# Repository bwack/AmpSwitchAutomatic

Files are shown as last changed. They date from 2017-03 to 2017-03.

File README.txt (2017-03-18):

Amp Switch Automatic,
6 amplifiers connected to one pair of stereo speakers with
automatic switching.

Realized with 1970-80s digital logic technology on two stripboards, and
a project box with 28 speaker terminals on it and a 5V power input.

Cheepo auto 1:1 600:600 ohm audio transformers were used to galvanically
isolate the amplifiers, and to pass audio to the detector circuits (lm339).
The relays switch the amplifiers in one at a time. If there is audio on
more than one amplifier, the amp switch sticks to the currently switched amp,
just to keep the box from switching too much. It is not intended to mix,
just switch though.

Bwack, 2017

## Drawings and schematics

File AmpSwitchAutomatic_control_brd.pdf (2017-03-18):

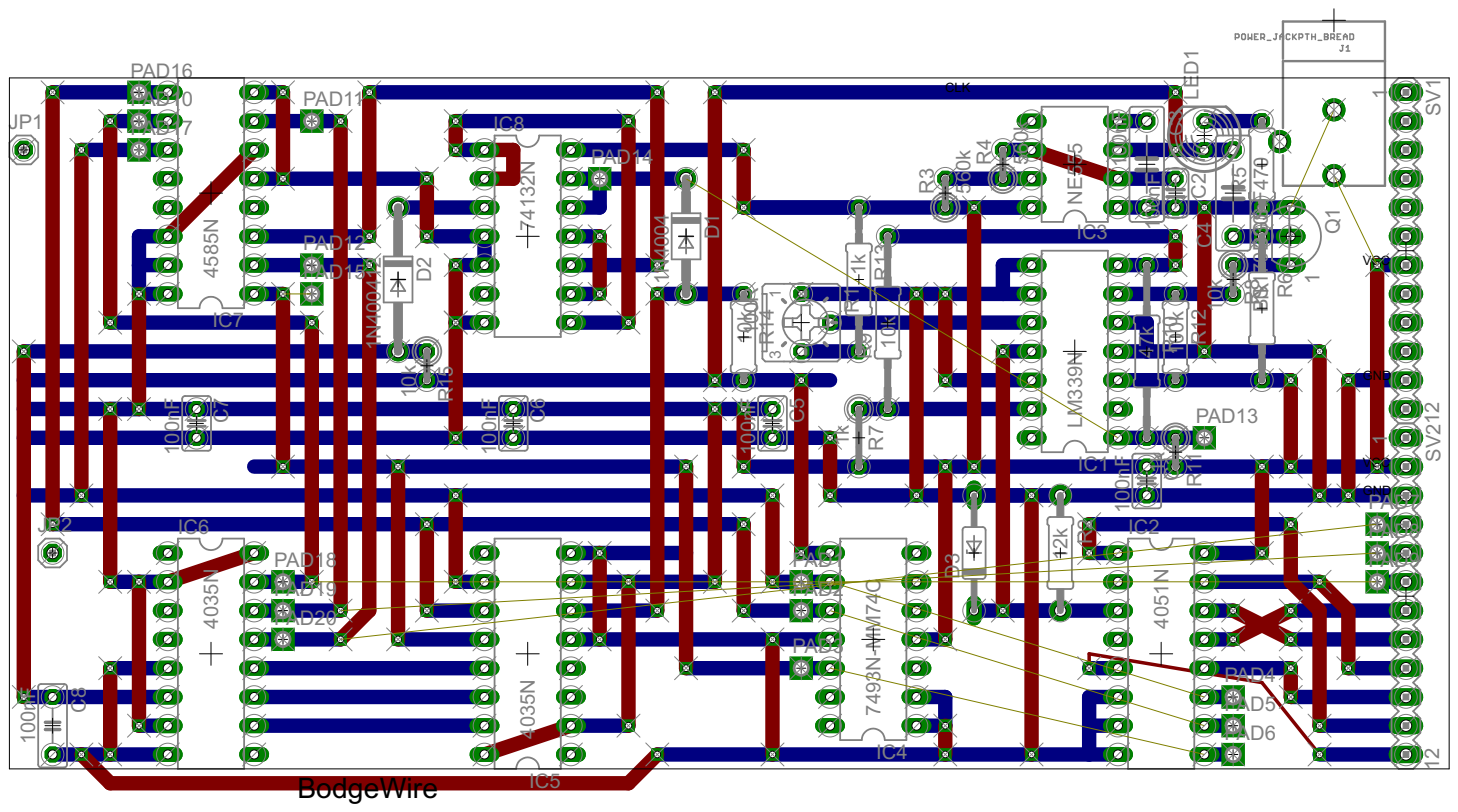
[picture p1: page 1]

1 12 1 12 3 1 1 SV1 SV2 IC1 IC2 R2 C1 IC3 R3R4 C2 C3 LED1 R5 R6 C4 R7 R8 R9R10 R11 R1 R2 1 R13 IC4 IC5 R14 D1 IC6 IC7 IC8 D2 R15 C5C6C7 Q1 PAD1 PAD2 PAD3 PAD4 PAD5 PAD6 PAD7 PAD8 PAD9 PAD10 PAD11 PAD12 D3 PAD13 PAD14 PAD15 PAD16 PAD17 PAD18 PAD19 PAD20 JP1JP2 C8 LM339N 4051N 12k 100nF NE555 560k560k 100nF 100nF 470 1k 330nF 1k 10k 10k 47k 1k 100k 100R 1k 7493N-MM74C 4035N 10k 1N4004 4035N 4585N74132N 1N400412 10k 100nF 100nF 100nF BS170DGS 100nF VCC VCC GND GND CLK BodgeWire

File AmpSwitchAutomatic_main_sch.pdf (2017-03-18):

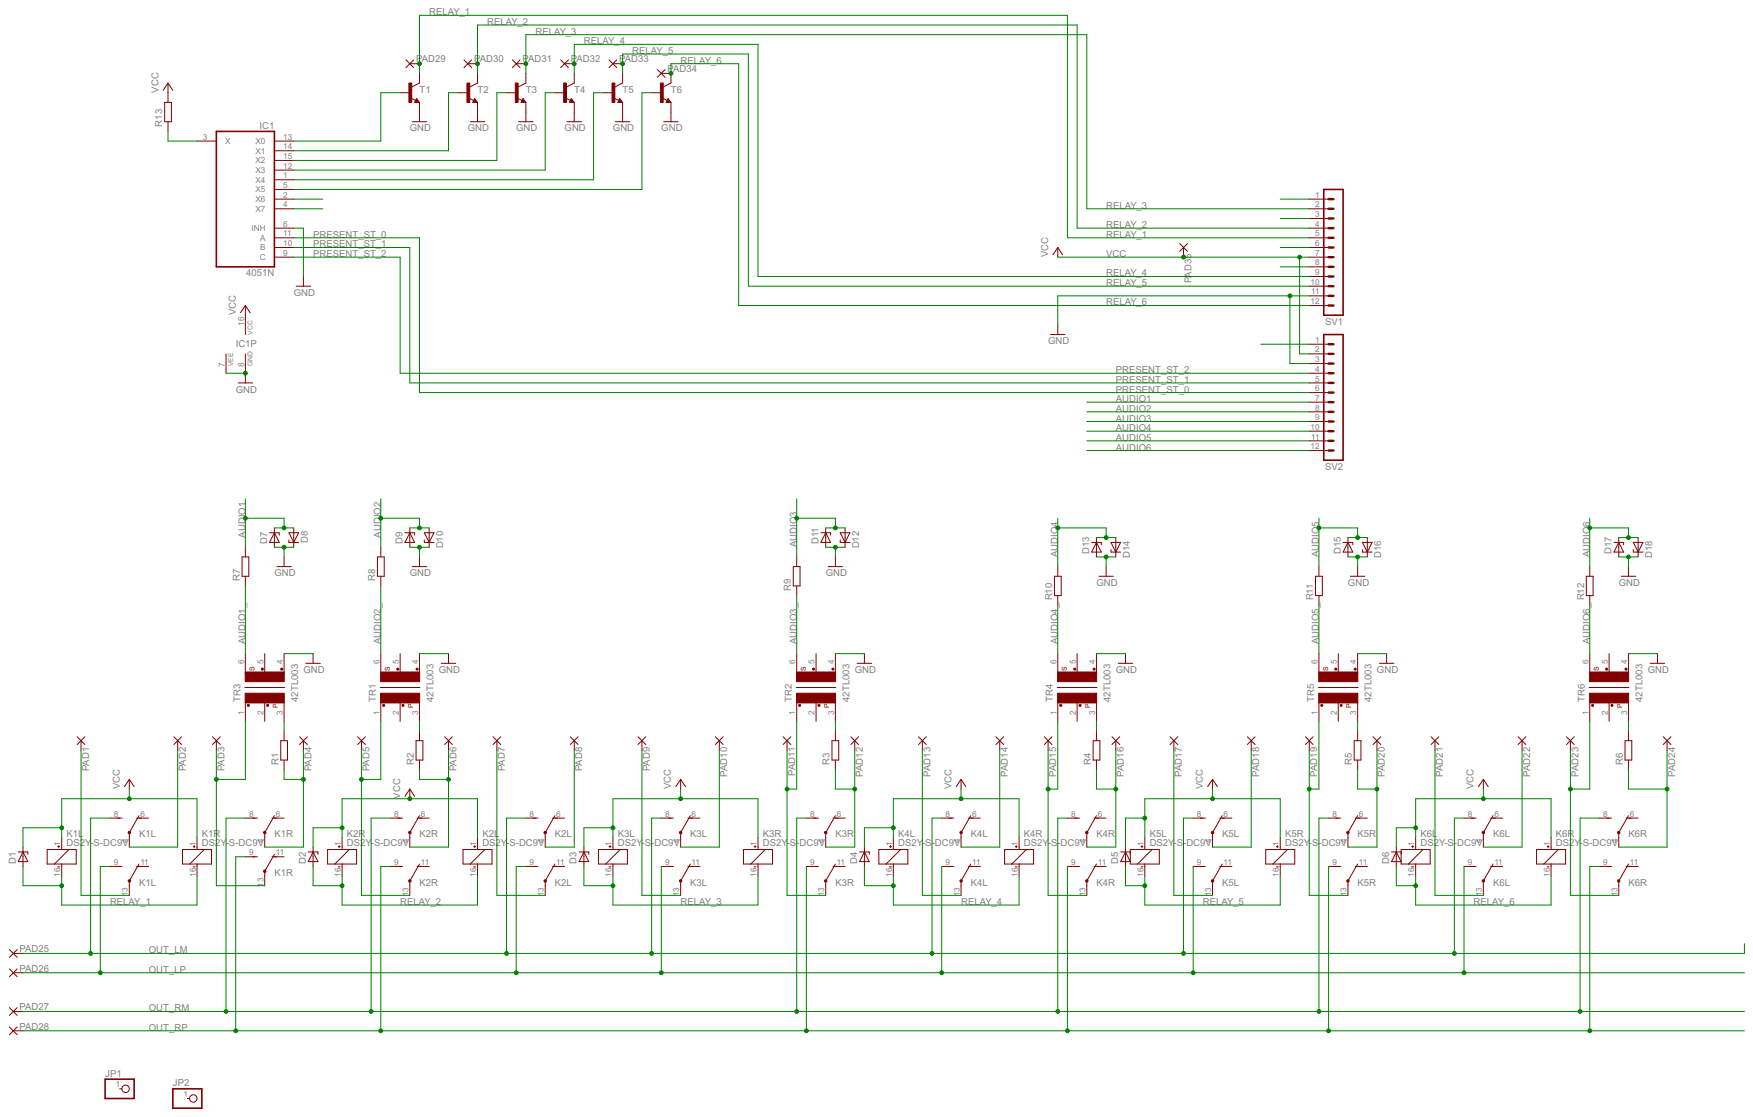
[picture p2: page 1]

RELAY_3

RELAY_4

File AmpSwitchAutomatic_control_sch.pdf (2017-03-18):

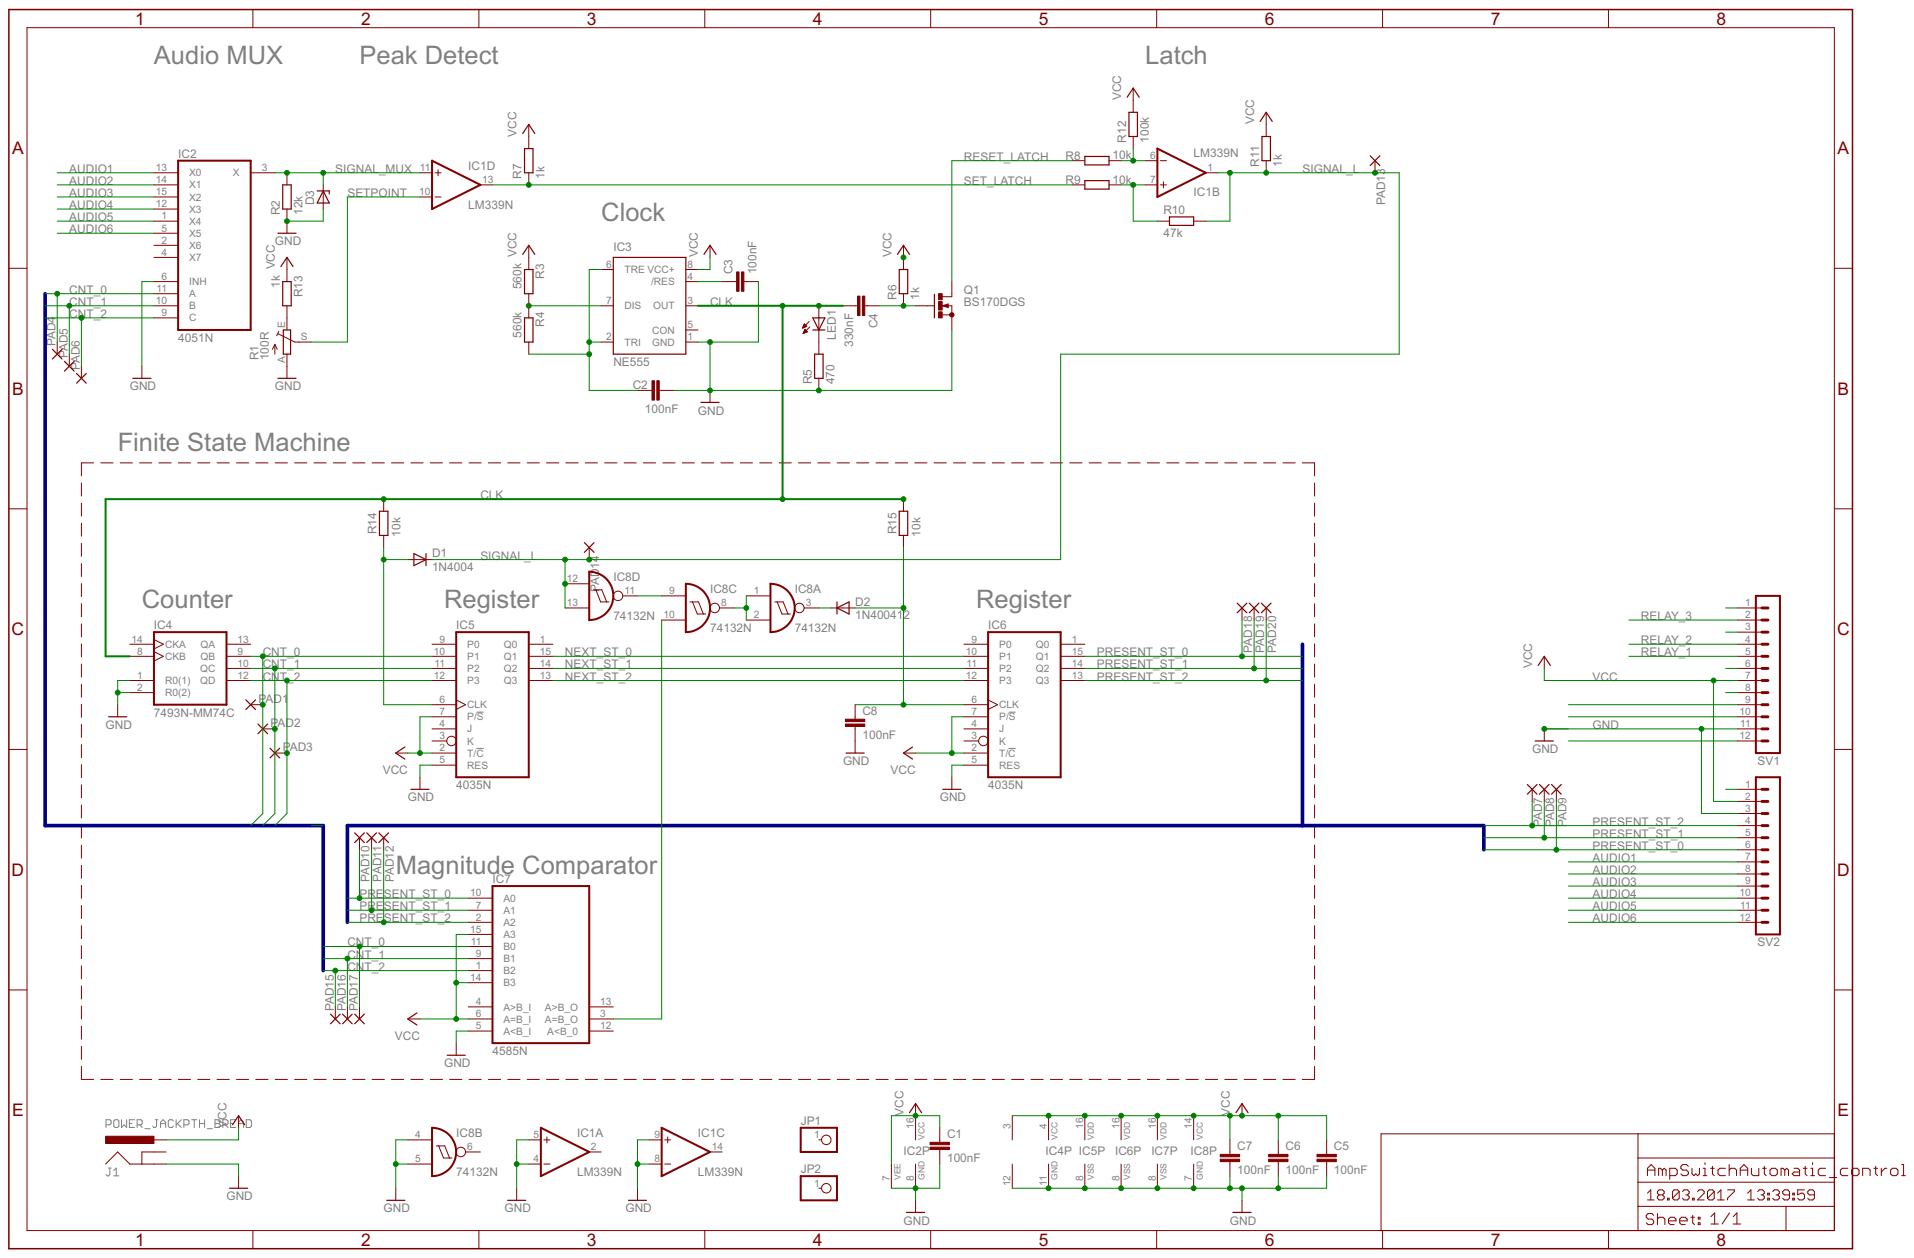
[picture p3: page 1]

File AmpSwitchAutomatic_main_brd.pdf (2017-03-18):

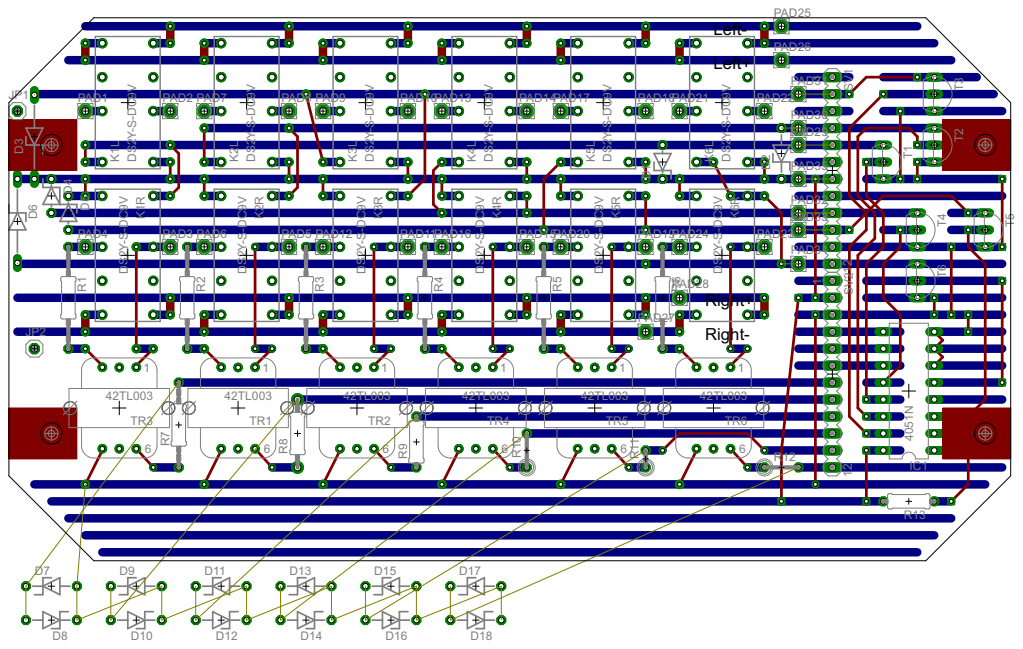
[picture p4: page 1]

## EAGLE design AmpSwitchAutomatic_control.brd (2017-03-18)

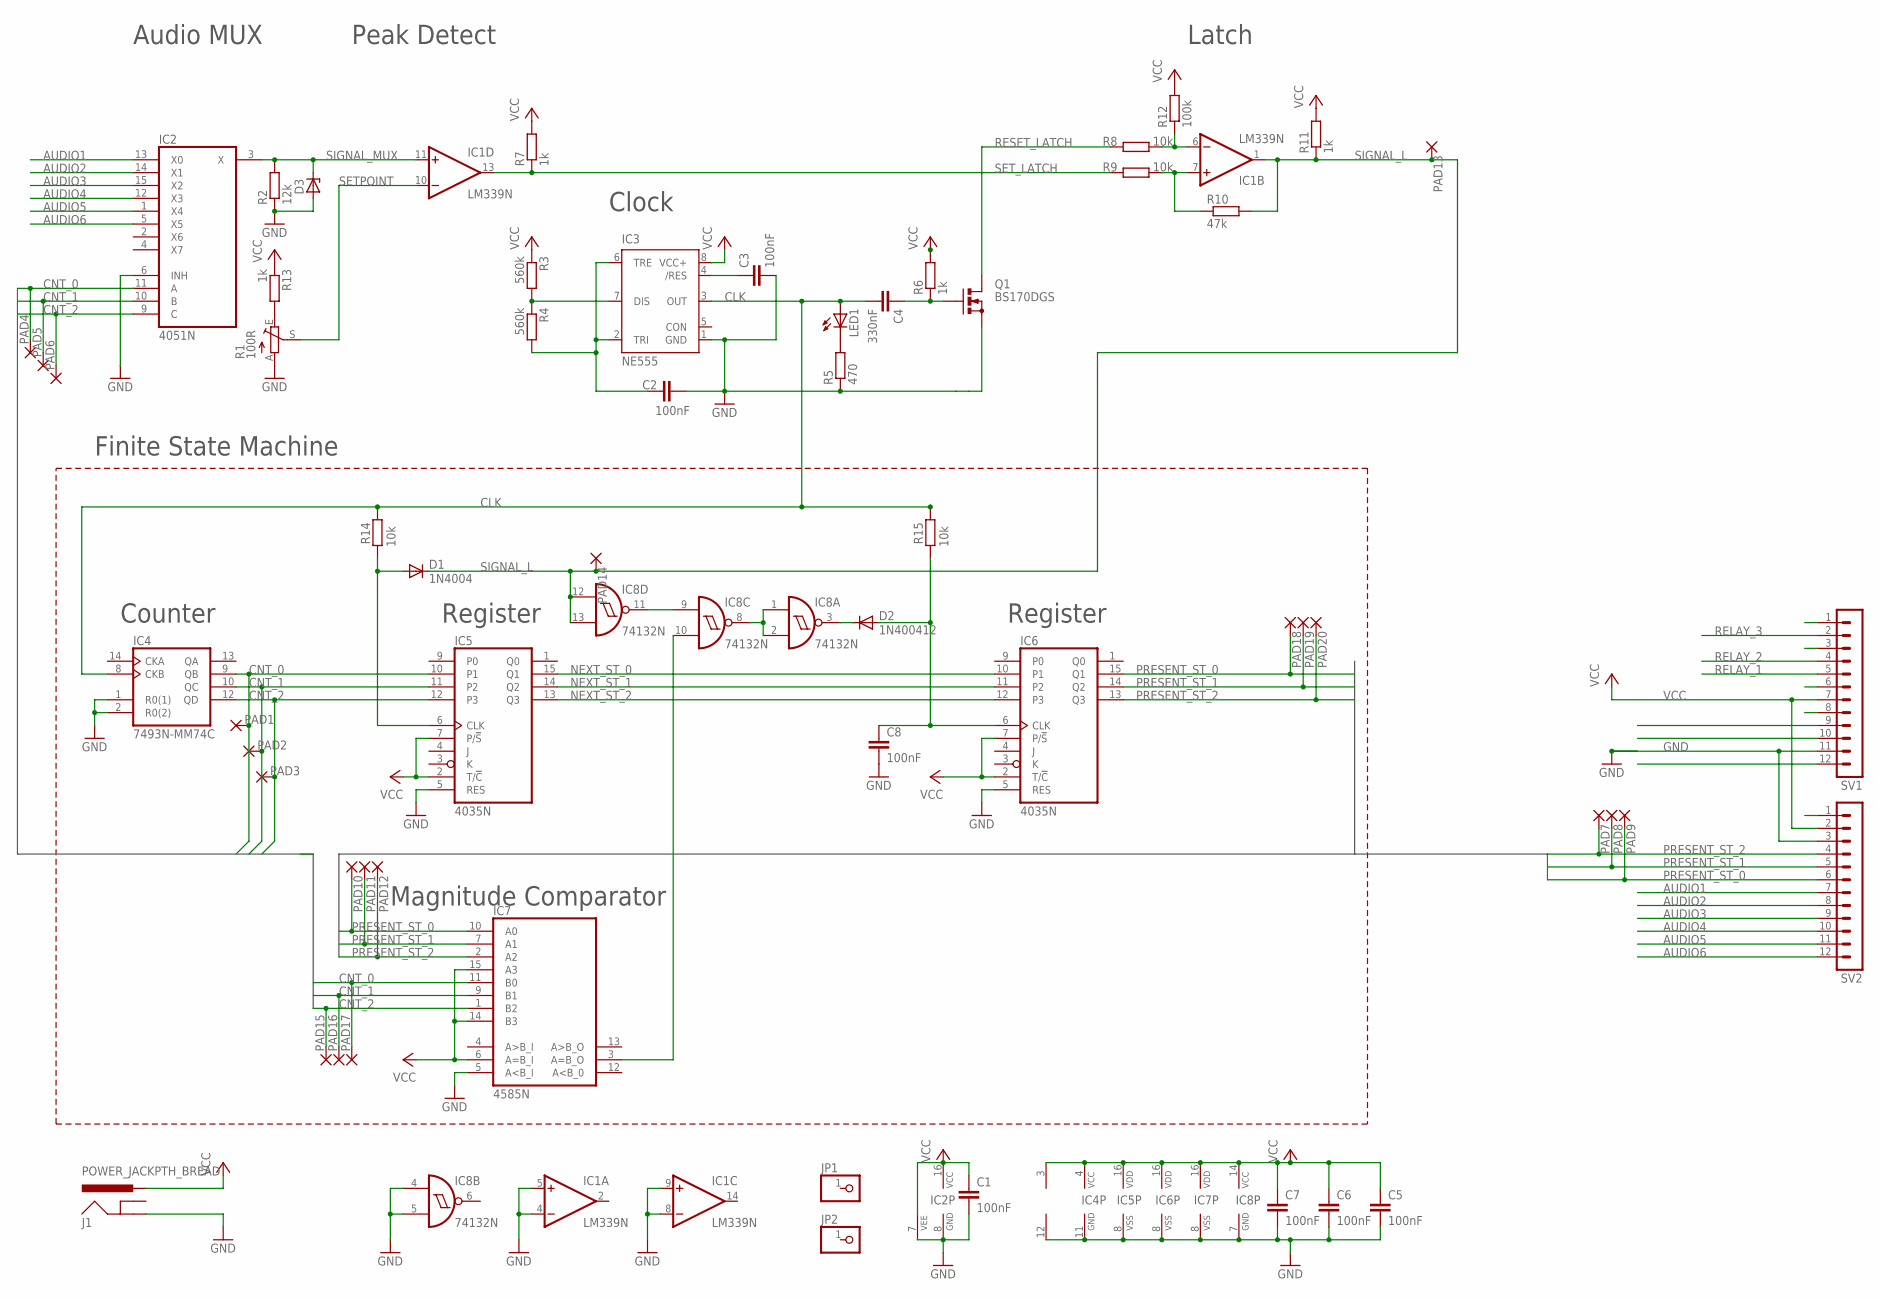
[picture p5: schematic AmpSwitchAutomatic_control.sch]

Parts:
C1, C5, C6, C7: 100nF; C025-025X050
C2, C3: 100nF; C025-024X044
C4: 330nF; C075-032X103
C8: 100nF; C050-025X075
D1: 1N4004; DO41-10
D2: 1N400412; DO41-12
D3: ZENER-DIODEDO35Z10; DO35Z10
IC1: LM339N; DIL14
IC2: 4051N; DIL16
IC3: NE555; DIL-08
IC4: 7493N-MM74C; DIL14
IC5, IC6: 4035N; DIL16
IC7: 4585N; DIL16
IC8: 74132N; DIL14
J1: POWER_JACKPTH_BREAD; POWER_JACK_PTH_BREAD
JP1, JP2: PINHD-1X1; 1X01
LED1: LED5MM
PAD1, PAD2, PAD3, PAD4, PAD5, PAD6, PAD7, PAD8, PAD9, PAD10, PAD11, PAD12, PAD13, PAD14, PAD15, PAD16, PAD17, PAD18, PAD19, PAD20: WIREPAD1,6/0,9; 1,6/0,9
Q1: BS170DGS; TO92-LINE
R1: 100R; B25P
R2: 12k; 0207/10
R3, R4: 560k; 0207/2V
R5: 470; 0207/15
R6: 1k; 0207/12
R7, R11: 1k; 0207/5V
R8: 10k; 0207/5V
R9: 10k; 0207/15
R10: 47k; 0207/15
R12: 100k; 0207/7
R13: 1k; 0207/7
R14: 10k; 0207/7
R15: 10k; 0207/2V
SV1, SV2: MA12-1

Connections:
AUDIO1: IC2.13 (X0), SV2.7
AUDIO2: IC2.14 (X1), SV2.8
AUDIO3: IC2.15 (X2), SV2.9
AUDIO4: IC2.12 (X3), SV2.10
AUDIO5: IC2.1 (X4), SV2.11
AUDIO6: IC2.5 (X5), SV2.12
CLK: C4.2, IC3.3 (OUT), IC4.8 (CKB), LED1.A, R14.2, R15.2
CNT_0: IC2.11 (A), IC4.9 (QB), IC5.10 (P1), IC7.11 (B0), PAD1.1, PAD4.1, PAD17.1
CNT_1: IC2.10 (B), IC4.10 (QC), IC5.11 (P2), IC7.9 (B1), PAD2.1, PAD5.1, PAD16.1
CNT_2: IC2.9 (C), IC4.12 (QD), IC5.12 (P3), IC7.1 (B2), PAD3.1, PAD6.1, PAD15.1
GND: C1.2, C2.2, C3.2, C5.2, C6.2, C7.2, C8.2, D3.A, IC1.4 (-IN), IC1.5 (+IN), IC1.8 (-IN), IC1.9 (+IN), IC1.12 (GND), IC2.6 (INH), IC2.7 (VEE), IC2.8 (GND), IC3.1 (GND), IC4.1 (R0(1)), IC4.2 (R0(2)), IC4.11 (GND), IC5.5 (RES), IC5.8 (VSS), IC6.5 (RES), IC6.8 (VSS), IC7.5 (A<B_I), IC7.8 (VSS), IC8.4 (I0), IC8.5 (I1), IC8.7 (GND), J1.GND, Q1.3 (S), R1.A, R2.1, R5.1, SV1.11, SV2.3
unnamed: R1.E, R13.2
unnamed: IC3.7 (DIS), R3.2, R4.1
unnamed: C2.1, IC3.2 (TRI), IC3.6 (TRE), R4.2
unnamed: LED1.K (C), R5.2
unnamed: C4.1, Q1.2 (G), R6.1
unnamed: IC1.6 (-IN), R8.2, R12.1
unnamed: IC1.7 (+IN), R9.2, R10.1
unnamed: C3.1, IC3.4 (/RES)
unnamed: D1.A, IC5.6 (CLK), R14.1
unnamed: D2.C, IC8.3 (O)
unnamed: C8.1, D2.A, IC6.6 (CLK), R15.1
unnamed: IC7.3 (A=B_O), IC8.10 (I1)
unnamed: IC8.1 (I0), IC8.2 (I1), IC8.8 (O)
unnamed: IC8.9 (I0), IC8.11 (O)
NEXT_ST_0: IC5.15 (Q1), IC6.10 (P1)
NEXT_ST_1: IC5.14 (Q2), IC6.11 (P2)
NEXT_ST_2: IC5.13 (Q3), IC6.12 (P3)
PRESENT_ST_0: IC6.15 (Q1), IC7.10 (A0), PAD9.1, PAD10.1, PAD18.1, SV2.6
PRESENT_ST_1: IC6.14 (Q2), IC7.7 (A1), PAD8.1, PAD11.1, PAD19.1, SV2.5
PRESENT_ST_2: IC6.13 (Q3), IC7.2 (A2), PAD7.1, PAD12.1, PAD20.1, SV2.4
RELAY_1: SV1.5
RELAY_2: SV1.4
RELAY_3: SV1.2
RESET_LATCH: Q1.1 (D), R8.1
SETPOINT: IC1.10 (-IN), R1.S
SET_LATCH: IC1.13 (OUT), R7.1, R9.1
SIGNAL_L: D1.C, IC1.1 (OUT), IC8.12 (I0), IC8.13 (I1), PAD13.1, PAD14.1, R10.2, R11.1
SIGNAL_MUX: D3.C, IC1.11 (+IN), IC2.3 (X), R2.2
VCC: C1.1, C5.1, C6.1, C7.1, IC1.3 (V+), IC2.16 (VCC), IC3.8 (VCC+), IC4.4 (VCC), IC5.2 (T/!C), IC5.7 (P/!S), IC5.16 (VDD), IC6.2 (T/!C), IC6.7 (P/!S), IC6.16 (VDD), IC7.6 (A=B_I), IC7.14 (B3), IC7.15 (A3), IC7.16 (VDD), IC8.14 (VCC), J1.PWR, R3.1, R6.2, R7.2, R11.2, R12.2, R13.1, SV1.7, SV2.2

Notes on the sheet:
Audio MUX
Peak Detect
Latch
Clock
Finite State Machine
Counter
Register
Magnitude Comparator

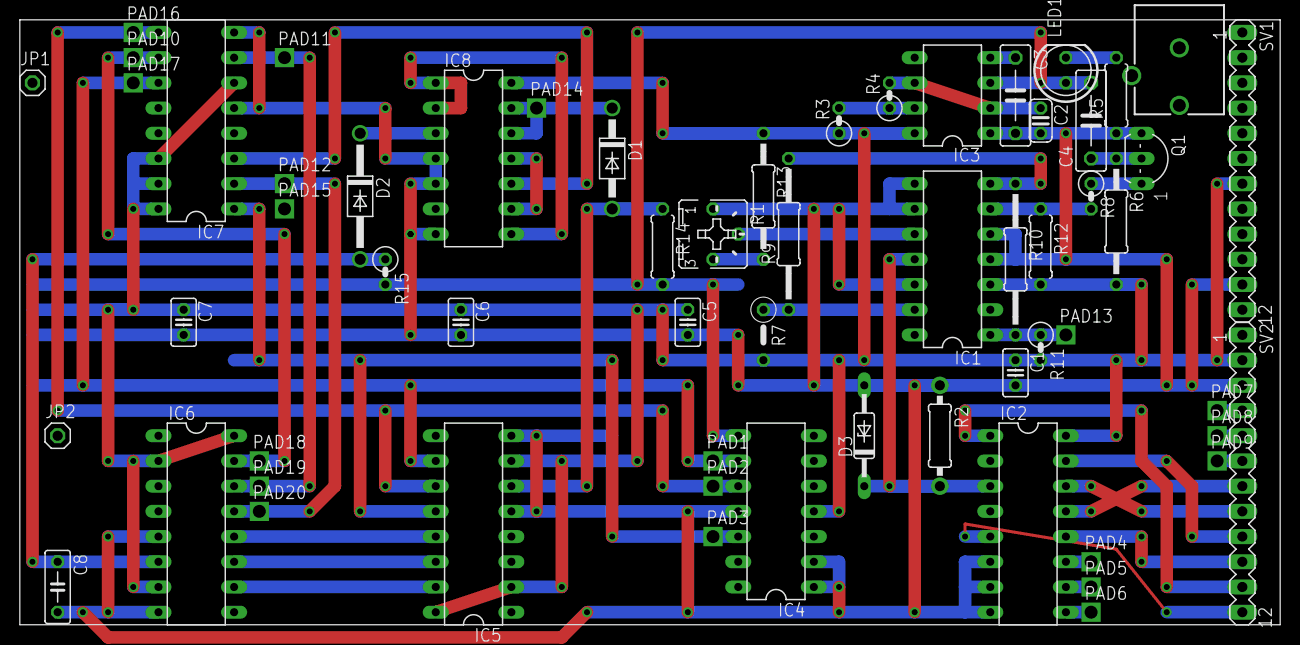
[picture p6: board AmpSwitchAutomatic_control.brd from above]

Board: 2 copper layers, 127.0 x 61.0 mm, 61 parts (0 on the bottom side), 37 nets.

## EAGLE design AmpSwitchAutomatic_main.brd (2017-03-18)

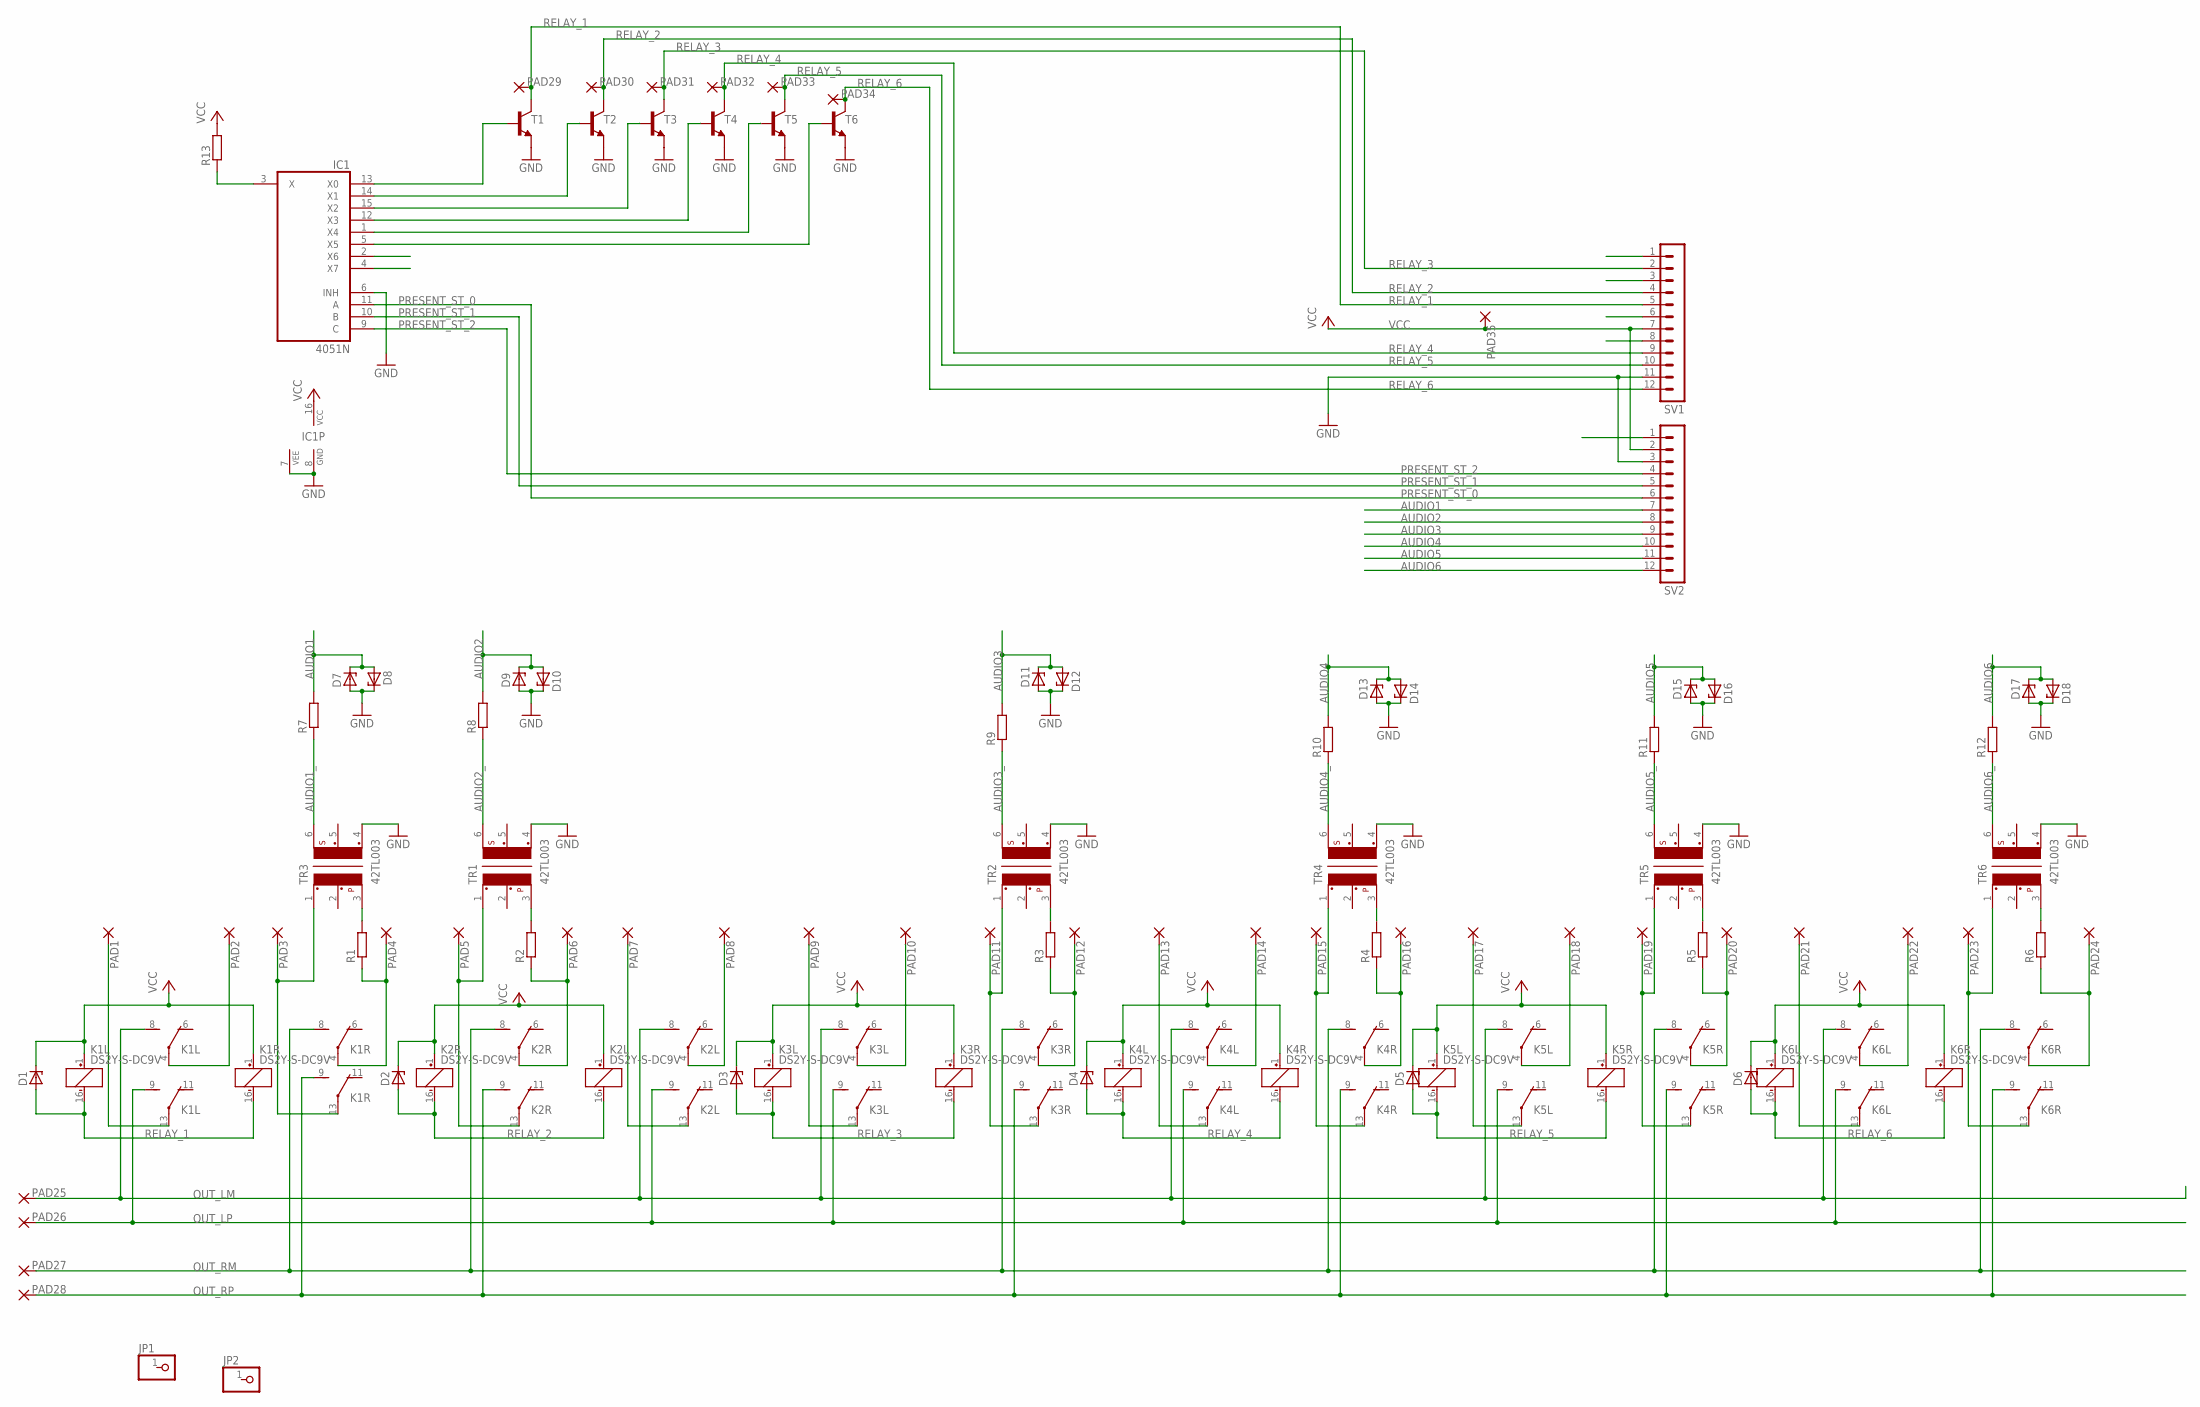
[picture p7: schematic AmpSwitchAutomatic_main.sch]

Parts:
D1, D4, D5: ZENER-DIODEZD-5; ZDIO-5
D2, D7, D8, D9, D10, D11, D12, D13, D14, D15, D16, D17, D18: ZENER-DIODEZD-7.5; ZDIO-7.5
D3, D6: ZENER-DIODEZD-12.5; ZDIO12.5
IC1: 4051N; DIL16
JP1, JP2: PINHD-1X1; 1X01
K1L: DS2Y-S-DC9V; DS2Y
K1R, K2L, K2R, K3L, K3R, K4L, K4R, K5L, K5R, K6L, K6R: DS2Y-S-DC9V; DS2Y; MPN DS2Y-S-DC9V
PAD1, PAD2, PAD3, PAD4, PAD5, PAD6, PAD7, PAD8, PAD9, PAD10, PAD11, PAD12, PAD13, PAD14, PAD15, PAD16, PAD17, PAD18, PAD19, PAD20, PAD21, PAD22, PAD23, PAD24, PAD25, PAD26, PAD27, PAD28, PAD29, PAD30, PAD31, PAD32, PAD33, PAD34, PAD35: WIREPAD2,15/1,0; 2,15/1,0
R1, R2, R3, R4, R5, R6: R-EU_0207/15; 0207/15
R7: R-EU_0207/12; 0207/12
R8: R-EU_0207/10; 0207/10
R9, R13: R-EU_0207/7; 0207/7
R10, R12: R-EU_0207/5V; 0207/5V
R11: R-EU_0207/2V; 0207/2V
SV1, SV2: MA12-1
T1, T2, T3, T4, T5, T6: 2N4124-NPN-TO92-CBE; TO92-CBE
TR1, TR2, TR3, TR4, TR5, TR6: 42TL003; 42TL

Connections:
AUDIO1: D7.C, D8.A, R7.2, SV2.7
AUDIO1_: R7.1, TR3.6
AUDIO2: D9.C, D10.A, R8.2, SV2.8
AUDIO2_: R8.1, TR1.6
AUDIO3: D11.C, D12.A, R9.2, SV2.9
AUDIO3_: R9.1, TR2.6
AUDIO4: D13.C, D14.A, R10.2, SV2.10
AUDIO4_: R10.1, TR4.6
AUDIO5: D15.C, D16.A, R11.2, SV2.11
AUDIO5_: R11.1, TR5.6
AUDIO6: D17.C, D18.A, R12.2, SV2.12
AUDIO6_: R12.1, TR6.6
GND: D7.A, D8.C, D9.A, D10.C, D11.A, D12.C, D13.A, D14.C, D15.A, D16.C, D17.A, D18.C, IC1.6 (INH), IC1.7 (VEE), IC1.8 (GND), SV1.11, SV2.3, T1.E, T2.E, T3.E, T4.E, T5.E, T6.E, TR1.4, TR2.4, TR3.4, TR4.4, TR5.4, TR6.4
unnamed: K3R.4, PAD12.1, R3.1
unnamed: K4L.13, PAD13.1
unnamed: K1L.13, PAD1.1
unnamed: K2L.13, PAD7.1
unnamed: K1L.4, PAD2.1
unnamed: K3L.13, PAD9.1
unnamed: K1R.13, PAD3.1, TR3.1
unnamed: K1R.4, PAD4.1, R1.1
unnamed: K3L.4, PAD10.1
unnamed: K4L.4, PAD14.1
unnamed: K2R.13, PAD5.1, TR1.1
unnamed: R1.2, TR3.3
unnamed: R2.2, TR1.3
unnamed: R3.2, TR2.3
unnamed: K3R.13, PAD11.1, TR2.1
unnamed: K2R.4, PAD6.1, R2.1
unnamed: R4.2, TR4.3
unnamed: K4R.13, PAD15.1, TR4.1
unnamed: K4R.4, PAD16.1, R4.1
unnamed: R5.2, TR5.3
unnamed: K2L.4, PAD8.1
unnamed: R6.2, TR6.3
unnamed: IC1.3 (X), R13.1
unnamed: IC1.13 (X0), T1.B
unnamed: IC1.14 (X1), T2.B
unnamed: K5L.13, PAD17.1
unnamed: K5L.4, PAD18.1
unnamed: K5R.13, PAD19.1, TR5.1
unnamed: K5R.4, PAD20.1, R5.1
unnamed: K6L.13, PAD21.1
unnamed: K6L.4, PAD22.1
unnamed: K6R.13, PAD23.1, TR6.1
unnamed: K6R.4, PAD24.1, R6.1
unnamed: IC1.15 (X2), T3.B
unnamed: IC1.12 (X3), T4.B
unnamed: IC1.1 (X4), T5.B
unnamed: IC1.5 (X5), T6.B
OUT_LM: K1L.8 (S), K2L.8 (S), K3L.8 (S), K4L.8 (S), K5L.8 (S), K6L.8 (S), PAD25.1
OUT_LP: K1L.9 (S), K2L.9 (S), K3L.9 (S), K4L.9 (S), K5L.9 (S), K6L.9 (S), PAD26.1
OUT_RM: K1R.8 (S), K2R.8 (S), K3R.8 (S), K4R.8 (S), K5R.8 (S), K6R.8 (S), PAD27.1
OUT_RP: K1R.9 (S), K2R.9 (S), K3R.9 (S), K4R.9 (S), K5R.9 (S), K6R.9 (S), PAD28.1
PRESENT_ST_0: IC1.11 (A), SV2.6
PRESENT_ST_1: IC1.10 (B), SV2.5
PRESENT_ST_2: IC1.9 (C), SV2.4
RELAY_1: D1.A, K1L.16 (-), K1R.16 (-), PAD29.1, SV1.5, T1.C
RELAY_2: D2.A, K2L.16 (-), K2R.16 (-), PAD30.1, SV1.4, T2.C
RELAY_3: D3.A, K3L.16 (-), K3R.16 (-), PAD31.1, SV1.2, T3.C
RELAY_4: D4.A, K4L.16 (-), K4R.16 (-), PAD32.1, SV1.9, T4.C
RELAY_5: D5.A, K5L.16 (-), K5R.16 (-), PAD33.1, SV1.10, T5.C
RELAY_6: D6.A, K6L.16 (-), K6R.16 (-), PAD34.1, SV1.12, T6.C
VCC: D1.C, D2.C, D3.C, D4.C, D5.C, D6.C, IC1.16 (VCC), K1L.1 (+), K1R.1 (+), K2L.1 (+), K2R.1 (+), K3L.1 (+), K3R.1 (+), K4L.1 (+), K4R.1 (+), K5L.1 (+), K5R.1 (+), K6L.1 (+), K6R.1 (+), PAD35.1, R13.2, SV1.7, SV2.2

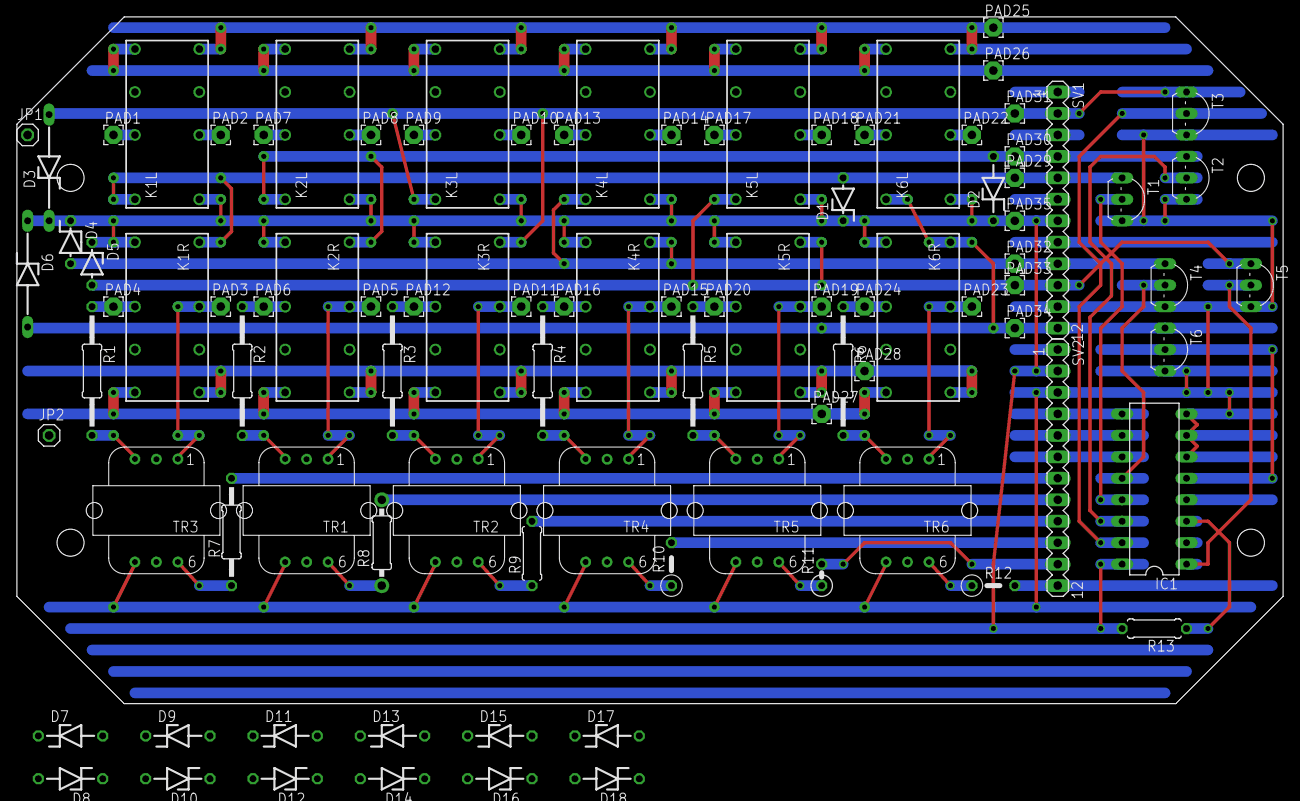
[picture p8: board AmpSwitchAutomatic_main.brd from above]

Board: 2 copper layers, 149.9 x 81.3 mm, 95 parts (0 on the bottom side), 64 nets.

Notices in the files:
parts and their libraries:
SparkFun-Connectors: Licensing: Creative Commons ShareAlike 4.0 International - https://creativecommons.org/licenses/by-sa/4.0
